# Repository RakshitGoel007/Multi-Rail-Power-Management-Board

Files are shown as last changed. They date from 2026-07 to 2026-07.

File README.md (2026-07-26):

# Multi-Rail Power Management Board

LTspice and KiCad portfolio project for a sequenced three-rail power-management block.

## Project Summary

This project converts a single 5 V input into three sequenced rails for an SoC + sensor cluster:

| Rail | Voltage | Purpose | Enable Time |
| --- | ---: | --- | ---: |
| Rail A | 1.2 V | SoC core | 0 ms |
| Rail B | 1.8 V | I/O logic | 2 ms |
| Rail C | 3.3 V | Sensors/camera | 4 ms |

The design includes input protection, regulator-stage modeling, output capacitance, equivalent loads, enable sequencing, Rail C load-step simulation, KiCad schematic capture, BOM files, and interview/report documentation.

## Repository Layout

```text
ltspice/   LTspice schematics, netlist, symbols, and vendor model files
kicad/     KiCad schematic project, symbol library, ERC report, exports
docs/      complete report, interview Q&A, portfolio summary, run guide
results/   simulation plots
bom/       project BOM
```

## Main Files

- `ltspice/PowerRails_Behavioral_Complete.asc`
- `ltspice/PowerRails_Behavioral_Complete.cir`
- `kicad/PowerRailsBoard_KiCad/PowerRailsBoard.kicad_pro`
- `kicad/PowerRailsBoard_KiCad/PowerRailsBoard.kicad_sch`
- `docs/Exhaustive_Project_Report.md`
- `docs/Exhaustive_Project_Report.pdf`
- `docs/Comprehensive_Interview_QA.md`
- `docs/Comprehensive_Interview_QA.pdf`
- `docs/Complete_Report_and_Interview_QA.pdf`
- `docs/Complete_Project_Report.md`
- `docs/Interview_Questions_and_Answers.md`
- `results/PowerRails_Sequencing_Plot.png`
- `results/RailC_Load_Transient_Plot.png`

## Validation

KiCad ERC result:

```text
0 errors, 0 warnings
```

The LTspice behavioral simulation is the recommended starting point because it does not depend on fragile vendor-symbol setup. Plot:

```text
V(RAIL_A_1V2)
V(RAIL_B_1V8)
V(RAIL_C_3V3)
V(EN_A)
V(EN_B)
V(EN_C)
```

## Engineering Note

The regulator part numbers are used for modeling and schematic practice. Before PCB fabrication, final regulator current ratings, thermal limits, package choices, and datasheet application circuits must be rechecked against the actual load requirements.

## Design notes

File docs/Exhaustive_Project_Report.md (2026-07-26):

# Exhaustive Project Report: Multi-Rail Power Management Board

Prepared for: Rakshit Goel  
Project type: hardware design, power electronics, schematic capture, simulation, and interview portfolio  
Main tools: LTspice, KiCad, TI regulator models, datasheets, behavioral simulation  
Repository: `Multi-Rail-Power-Management-Board`

## 1. Project Overview

This project is a multi-rail power management design for a small embedded system made from an SoC and a sensor/camera cluster. The board takes a single 5 V input and generates three regulated voltage rails:

| Rail | Voltage | Intended Load | Enable Order |
| --- | ---: | --- | ---: |
| Rail A | 1.2 V | SoC core logic | First |
| Rail B | 1.8 V | I/O logic, memory interface, IMU-style devices | Second |
| Rail C | 3.3 V | sensors, camera, peripheral modules | Third |

The core idea is not just to generate voltages. The project demonstrates an engineering workflow:

- define voltage/current requirements,
- choose a power architecture,
- model startup sequencing,
- simulate load transient behavior,
- capture a readable KiCad schematic,
- include protection and test points,
- prepare documentation and interview explanation material.

The project is portfolio-oriented. It is designed to show that the designer understands both circuit behavior and the practical workflow of building and explaining a hardware subsystem.

## 2. What The Project Does

At a system level, the project does the following:

1. Accepts a nominal 5 V input supply.
2. Provides reverse-polarity protection at the input.
3. Generates a 1.2 V rail for SoC core logic.
4. Generates a 1.8 V rail for I/O logic and low-voltage peripherals.
5. Generates a 3.3 V rail for sensors/camera/peripherals.
6. Sequences the rails in a controlled order.
7. Adds output capacitors to support transient current demand.
8. Adds equivalent loads for simulation and validation.
9. Adds a Rail C load-step event to represent a sensor/camera waking up.
10. Adds enable monitor signals so startup timing can be plotted clearly.
11. Provides a KiCad schematic with test points and a BOM.
12. Exports a schematic PDF, SVG/PNG preview, netlist, BOM, and ERC report.
13. Provides a complete report and interview question bank.

The LTspice simulation focuses on startup behavior and load transient response. The KiCad schematic focuses on readability, design intent, component organization, and bring-up/debug access.

## 3. Why Multi-Rail Power Exists

Modern embedded systems rarely run from one supply voltage. A typical SoC may have:

- a low-voltage core supply for internal logic,
- a separate I/O supply for interface pins,
- a higher peripheral supply for sensors, cameras, RF modules, or analog front ends.

Using separate rails allows each subsystem to receive the voltage it needs. It also improves control over noise, sequencing, power consumption, and debugging.

In this project:

- 1.2 V represents a core rail.
- 1.8 V represents an I/O rail.
- 3.3 V represents a peripheral/sensor rail.

This is a realistic split for many embedded boards.

## 4. Design Requirements

### 4.1 Electrical Requirements

| Requirement | Target |
| --- | --- |
| Input voltage | 5 V nominal |
| Output Rail A | 1.2 V |
| Output Rail B | 1.8 V |
| Output Rail C | 3.3 V |
| Rail A current target | 500 mA equivalent |
| Rail B current target | 600 mA equivalent |
| Rail C current target | 800 mA transient case |
| Startup sequence | A first, B second, C third |
| Rail B delay | about 2 ms after Rail A |
| Rail C delay | about 4 ms after Rail A |
| Rail C load step | 0.1 A to 0.8 A at 8 ms |
| Simulation duration | 20 ms transient |

### 4.2 Functional Requirements

The project must:

- show clear startup sequencing,
- include realistic rail names,
- include output capacitance,
- model expected load conditions,
- include transient response observation,
- include test points,
- be explainable in an interview,
- open reliably in LTspice and KiCad.

### 4.3 Documentation Requirements

The project must include:

- a technical report,
- an interview Q&A bank,
- a one-page summary,
- instructions for opening and running,
- BOM files,
- simulation plots,
- schematic exports.

## 5. Power Architecture

The architecture is:

```text
5 V input
  |
  +--> input protection
  |
  +--> Rail A regulator --> 1.2 V core rail
  |
  +--> Rail B regulator --> 1.8 V I/O rail
  |
  +--> Rail C regulator/load switch --> 3.3 V sensor rail
```

Rail A comes up first because SoC internal logic should be alive before I/O and peripherals are powered. Rail B comes second because I/O pads often depend on the core domain being valid. Rail C comes third because sensors/cameras can draw significant current and should not be powered before the processor/I/O side is ready.

## 6. Rail Definitions

### 6.1 Rail A: 1.2 V Core

Rail A is the first rail. It represents the SoC core supply. Core rails often power CPU logic, internal state machines, memory controllers, PLL blocks, or digital logic.

Design intent:

- start at 0 ms,
- settle near 1.2 V,
- support an equivalent 500 mA load,
- provide a reference for later rails.

Equivalent load:

```text
R = V / I = 1.2 V / 0.5 A = 2.4 ohm
```

### 6.2 Rail B: 1.8 V I/O

Rail B is the second rail. It represents low-voltage I/O logic or peripheral interfaces.

Design intent:

- start around 2 ms,
- settle near 1.8 V,
- support an equivalent 600 mA load,
- avoid powering I/O before the core rail.

Equivalent load:

```text
R = V / I = 1.8 V / 0.6 A = 3.0 ohm
```

### 6.3 Rail C: 3.3 V Sensor Rail

Rail C is the third rail. It represents sensors, camera modules, and other 3.3 V peripherals.

Design intent:

- start around 4 ms,
- settle near 3.3 V,
- support a transient load jump,
- include a load-switch concept for peripheral control.

Full-load equivalent resistance:

```text
R = V / I = 3.3 V / 0.8 A = 4.125 ohm
```

In the main simulation, Rail C uses a current load-step model because that better represents a sensor or camera suddenly waking up.

## 7. Why Sequencing Matters

Power sequencing is important because ICs are not always tolerant of arbitrary rail order. Incorrect sequencing can cause:

- back-powering through I/O pins,
- current injection through ESD diodes,
- undefined boot states,
- latch-up risk,
- peripherals starting before the controller is ready,
- increased inrush current,
- failed reset behavior.

The intended startup order is:

```text
Rail A: 1.2 V core       t = 0 ms
Rail B: 1.8 V I/O        t = 2 ms
Rail C: 3.3 V sensors    t = 4 ms
```

For power-down, the preferred order is normally reverse:

```text
Rail C off first
Rail B off second
Rail A off last
```

This prevents peripherals and I/O from remaining powered while the core logic is unavailable.

## 8. Component-Level Design

### 8.1 Input Protection

The schematic includes `D1 SS34`, a Schottky diode used for reverse-polarity protection. The purpose is to protect the board if the input supply is accidentally connected backwards.

Advantages:

- simple,
- cheap,
- easy to understand,
- robust for a student-level schematic.

Disadvantages:

- forward voltage drop,
- power loss,
- heating at high current.

Power loss estimate:

```text
P = I * Vf
```

If current is 1 A and diode drop is 0.4 V:

```text
P = 1 A * 0.4 V = 0.4 W
```

For a production board, a P-MOSFET ideal-diode style reverse-protection circuit would be more efficient.

### 8.2 Regulator Stages

The guide-selected regulators/models are:

| Ref | Part | Purpose |
| --- | --- | --- |
| U1 | TPS62203 | buck regulator reference for 3.3 V rail |
| U2 | TPS62240 | buck regulator reference for 1.8 V rail |
| U3 | TLV70012 | LDO reference for 1.2 V rail |

Important caveat:

The selected part numbers are useful for model practice and schematic learning, but a real fabricated board must verify regulator current ratings. If the actual rails require 500 mA, 600 mA, and 800 mA continuously, the selected parts may not all be suitable. A competent final design would select regulators with adequate current margin, thermal performance, and package capability.

### 8.3 Output Capacitors

Each rail uses a 22 uF output capacitor in the simulation. Output capacitors:

- reduce ripple,
- support transient load steps,
- improve local energy availability,
- affect regulator loop stability,
- reduce high-frequency impedance at the rail.

Ceramic X7R capacitors are used conceptually because they have good temperature behavior compared with lower-grade dielectrics.

Real-world note:

Ceramic capacitor effective capacitance decreases with DC bias. A 22 uF capacitor may behave like a much smaller capacitor at its operating voltage, depending on package and dielectric.

### 8.4 Equivalent Loads

Resistive loads are used for Rail A and Rail B:

| Rail | Voltage | Current | Load |
| --- | ---: | ---: | ---: |
| A | 1.2 V | 0.5 A | 2.4 ohm |
| B | 1.8 V | 0.6 A | 3.0 ohm |

Rail C includes a light load and a pulsed load step.

### 8.5 Rail C Load Step

Rail C models a sudden load increase:

```text
0.1 A light load -> 0.8 A active load
```

This represents a sensor/camera subsystem waking up or entering active mode.

The project measures:

- pre-step average voltage,
- minimum voltage during load step,
- recovered average voltage.

This shows whether the rail droops too much and whether it recovers.

### 8.6 Enable Monitor Signals

The LTspice schematic includes behavioral enable monitor sources:

```text
EN_A
EN_B
EN_C
```

These are not meant to be final production enable circuits. They are included so the startup sequence can be plotted clearly against the rail voltages.

In a real design, these enables could be produced by:

- RC delay circuits,
- power-good chaining,
- a microcontroller,
- a PMIC,
- a supervisor/sequencer IC.

## 9. LTspice Simulation

### 9.1 Main Files

```text
ltspice/PowerRails_Behavioral_Complete.asc
ltspice/PowerRails_Behavioral_Complete.cir
```

The `.asc` file is the visual schematic-style simulation. The `.cir` file is the companion plain netlist.

### 9.2 Why Behavioral Modeling Was Used

Vendor regulator models can be fragile. They may depend on exact subcircuit names, hidden pins, PSPICE compatibility, or symbol alignment. A behavioral model allows the project to validate the architecture first:

- startup order,
- expected output voltages,
- enable timing,
- load step behavior,
- measurement workflow.

The behavioral model is not a replacement for a final regulator simulation. It is a fast architecture-level verification step.

### 9.3 Behavioral Equations

The LTspice schematic uses function directives such as:

```spice
.func RA(t) if(t>=0,1.2,0)
.func RB(t) if(t>=2m,1.8,0)
.func RC(t) if(t>=4m,3.292,0)-if(t>=8m,if(t<12m,56m,0),0)
.func LOAD(t) if(t>=8m,if(t<12m,0.7,0),0)
```

This keeps the schematic visually clean because each behavioral source displays a short expression:

```spice
V=RA(time)
V=RB(time)
V=RC(time)
I=LOAD(time)
```

### 9.4 Simulation Command

```spice
.tran 20m startup
```

This runs a transient simulation from 0 ms to 20 ms and starts from supply startup conditions.

### 9.5 Signals To Plot

```text
V(RAIL_A_1V2)
V(RAIL_B_1V8)
V(RAIL_C_3V3)
V(EN_A)
V(EN_B)
V(EN_C)
I(IC_LOADSTEP)
```

### 9.6 Expected Results

Expected startup:

| Signal | Expected Behavior |
| --- | --- |
| `RAIL_A_1V2` | rises first to 1.2 V |
| `RAIL_B_1V8` | rises after about 2 ms |
| `RAIL_C_3V3` | rises after about 4 ms |
| `EN_A` | turns on at 0 ms |
| `EN_B` | turns on at 2 ms |
| `EN_C` | turns on at 4 ms |
| `I(IC_LOADSTEP)` | active around 8 ms to 12 ms |

### 9.7 Measurement Directives

The simulation includes:

```spice
.meas tran RailA_90pct_time WHEN V(RAIL_A_1V2)=1.08 RISE=1
.meas tran RailB_90pct_time WHEN V(RAIL_B_1V8)=1.62 RISE=1
.meas tran RailC_90pct_time WHEN V(RAIL_C_3V3)=2.97 RISE=1
.meas tran RailC_pre_step_avg AVG V(RAIL_C_3V3) FROM=7m TO=7.8m
.meas tran RailC_load_step_min MIN V(RAIL_C_3V3) FROM=8m TO=9m
.meas tran RailC_recovered_avg AVG V(RAIL_C_3V3) FROM=9m TO=12m
```

These measure:

- when each rail reaches 90% of nominal,
- Rail C voltage before the transient,
- Rail C minimum voltage during the load step,
- Rail C recovered average voltage after the step.

### 9.8 Acceptance Criteria

For this project:

- Rail A should reach 90% before Rail B begins.
- Rail B should reach 90% before Rail C begins.
- Rail C should show controlled droop during the load step.
- The simulation should be readable and repeatable.

For a production design, acceptance criteria would also include:

- ripple voltage limit,
- transient recovery time,
- overshoot limit,
- power-up monotonicity,
- thermal limit,
- efficiency target,
- EMI target.

## 10. KiCad Schematic Design

### 10.1 Main Files

```text
kicad/PowerRailsBoard_KiCad/PowerRailsBoard.kicad_pro
kicad/PowerRailsBoard_KiCad/PowerRailsBoard.kicad_sch
```

### 10.2 Exported Files

```text
kicad/PowerRailsBoard_KiCad/PowerRailsBoard_schematic.pdf
kicad/PowerRailsBoard_KiCad/PowerRailsBoard.svg.png
kicad/PowerRailsBoard_KiCad/PowerRailsBoard.net
kicad/PowerRailsBoard_KiCad/PowerRailsBoard_BOM_from_KiCad.csv
kicad/PowerRailsBoard_KiCad/ERC_report.txt
```

### 10.3 ERC Result

KiCad ERC result:

```text
0 errors, 0 warnings
```

This means the schematic has no KiCad-detected electrical rule problems in the current schematic-level representation.

### 10.4 What The KiCad Schematic Contains

The KiCad schematic includes:

- input connector,
- input reverse-polarity diode,
- input capacitor,
- regulator blocks,
- output capacitors,
- load resistors,
- Rail C P-MOSFET load switch,
- feedback divider representation,
- enable sequencing RC networks,
- test points,
- net labels,
- title notes.

### 10.5 Why Custom Symbols Were Used

The schematic uses custom local symbols in `RailProject.kicad_sym`. This reduces dependency issues. The schematic opens cleanly because it does not rely on missing external symbol libraries.

For a production schematic, the next step would be to replace simplified local regulator blocks with official manufacturer symbols and confirmed footprints.

## 11. BOM Summary

The BOM contains the main components:

| Ref | Part | Purpose |
| --- | --- | --- |
| U1 | TPS62203 | 3.3 V buck reference |
| U2 | TPS62240 | 1.8 V buck reference |
| U3 | TLV70012 | 1.2 V LDO reference |
| Q1 | AO3401 | P-MOSFET Rail C load switch |
| D1 | SS34 | reverse-polarity protection |
| C_IN | 10 uF X7R | input capacitor |
| C_OUT_A/B/C | 22 uF X7R | output capacitors |
| R_LOAD_A | 2.4 ohm | Rail A load |
| R_LOAD_B | 3.0 ohm | Rail B load |
| R_LOAD_C | 4.125 ohm/pulsed | Rail C load representation |

## 12. Important Engineering Caveats

### 12.1 Regulator Current Rating

The most important caveat is that the named parts must be checked against current requirements before fabrication. Model availability does not equal design suitability.

A stronger production design would select regulators with:

- rated output current above the maximum load,
- thermal margin,
- acceptable efficiency,
- available package and footprint,
- datasheet-supported inductor/capacitor values,
- stable control loop over expected load.

### 12.2 LDO Thermal Dissipation

If a 1.2 V rail is generated from 5 V using an LDO at 500 mA:

```text
P = (Vin - Vout) * I
P = (5 V - 1.2 V) * 0.5 A
P = 1.9 W
```

That is too high for many small packages. A real board would likely use a buck converter for 1.2 V or a two-stage approach.

### 12.3 Behavioral Simulation Limits

The behavioral LTspice model does not show:

- switching ripple,
- inductor current ripple,
- compensation loop behavior,
- switch-node ringing,
- layout parasitics,
- EMI,
- real startup soft-start details,
- regulator current limiting.

It is still valuable because it validates architecture and timing.

### 12.4 RC Sequencing Tolerance

RC delays are approximate. Real delays vary due to:

- resistor tolerance,
- capacitor tolerance,
- capacitor leakage,
- temperature,
- enable threshold variation,
- input ramp rate.

For production, a sequencer IC is more reliable.

## 13. PCB Layout Considerations

If this schematic is moved to PCB layout, key rules are:

1. Place input capacitors close to regulator VIN and GND pins.
2. Keep high-current loops short.
3. Keep buck switch nodes small.
4. Route feedback traces away from switch nodes.
5. Use a solid ground plane.
6. Use wide traces or pours for high-current rails.
7. Place output capacitors close to regulator outputs.
8. Keep analog/sensitive nodes away from noisy switching paths.
9. Add thermal copper for regulators and diode.
10. Keep test points accessible.

For a two-layer board, layout is possible but harder. For a cleaner power design, a four-layer board with solid ground and power planes is preferable.

## 14. Bring-Up Plan

### 14.1 Before Power-On

Check:

- visual inspection,
- diode orientation,
- capacitor polarity if any polarized parts exist,
- regulator pinout,
- shorts between each rail and ground,
- continuity of input and ground,
- correct component values.

### 14.2 First Power-On

Use:

- current-limited bench supply,
- low current limit at first,
- oscilloscope on rail test points,
- multimeter for steady-state checks.

Procedure:

1. Apply 5 V with low current limit.
2. Confirm no excessive current.
3. Measure `VIN_5V`.
4. Probe `EN_A`, `EN_B`, `EN_C`.
5. Probe `RAIL_A_1V2`, `RAIL_B_1V8`, `RAIL_C_3V3`.
6. Confirm order and final voltages.
7. Increase load slowly.
8. Test Rail C load transient.

### 14.3 Measurements To Capture

Capture:

- startup sequence waveform,
- rise time of each rail,
- final DC voltage,
- load transient droop,
- recovery time,
- ripple,
- regulator temperature.

## 15. Failure Modes And Debug Strategy

| Symptom | Possible Cause | Debug Step |
| --- | --- | --- |
| Rail missing | regulator disabled, wrong footprint, short, no input | check VIN and EN pin |
| Rail low | overload, wrong feedback, current limit | remove load, inspect feedback |
| Rail noisy | poor layout, missing capacitor, unstable loop | check capacitor placement and values |
| Startup wrong order | RC timing error, threshold variation | probe enable pins |
| Diode hot | excessive current or high voltage drop | measure current and diode drop |
| Rail C droops too much | insufficient capacitance or slow regulator | increase capacitance or choose faster regulator |
| Board current too high | short, wrong part orientation, load too heavy | current-limit and isolate rails |

## 16. Repository Deliverables

| Path | Purpose |
| --- | --- |
| `README.md` | GitHub landing page |
| `ltspice/PowerRails_Behavioral_Complete.asc` | main LTspice visual simulation |
| `ltspice/PowerRails_Behavioral_Complete.cir` | companion netlist |
| `ltspice/PowerRails_REAL.asc` | real-model starter schematic |
| `ltspice/*.asy` | LTspice symbols |
| `ltspice/*.lib` | LTspice model libraries |
| `kicad/PowerRailsBoard_KiCad/PowerRailsBoard.kicad_pro` | KiCad project |
| `kicad/PowerRailsBoard_KiCad/PowerRailsBoard.kicad_sch` | KiCad schematic |
| `kicad/PowerRailsBoard_KiCad/ERC_report.txt` | ERC validation |
| `kicad/PowerRailsBoard_KiCad/PowerRailsBoard_schematic.pdf` | schematic PDF export |
| `kicad/PowerRailsBoard_KiCad/PowerRailsBoard_BOM_from_KiCad.csv` | KiCad BOM export |
| `bom/PowerRails_BOM.csv` | project-level BOM |
| `results/PowerRails_Sequencing_Plot.png` | sequencing simulation plot |
| `results/RailC_Load_Transient_Plot.png` | load transient plot |
| `docs/Exhaustive_Project_Report.md` | detailed project report |
| `docs/Comprehensive_Interview_QA.md` | interview preparation bank |

## 17. What This Project Demonstrates

This project demonstrates:

- power rail planning,
- rail sequencing,
- load calculation,
- transient simulation,
- behavioral modeling,
- schematic organization,
- BOM creation,
- ERC checking,
- test point planning,
- awareness of real-world limitations,
- ability to communicate an engineering design.

The strongest interview point is that the project does not blindly claim perfection. It clearly separates:

- what is proven by the behavioral simulation,
- what is represented by the KiCad schematic,
- what must still be checked before fabrication.

That is how a competent engineer presents a design.

## 18. Short Interview Summary

This project is a multi-rail power management block for an SoC and sensor cluster. It takes a 5 V input and creates 1.2 V, 1.8 V, and 3.3 V rails. The rails are sequenced so the core rail turns on first, then I/O, then sensors. I simulated the startup sequence and a 3.3 V load transient in LTspice, captured an ERC-clean schematic in KiCad, included input protection, enable delay networks, output capacitors, loads, and test points, and documented the design limitations. The next production step would be replacing the learning-model regulator choices with current-rated regulators, assigning final footprints, doing PCB layout, and validating sequencing, ripple, transient response, and temperature on the bench.

## 19. Final Conclusion

The project successfully shows a complete power-management design workflow. It is not just a schematic; it includes requirements, architecture, simulation, schematic capture, validation exports, documentation, and interview preparation.

The design is appropriate as a university-level hardware portfolio project. It shows practical understanding of power sequencing, regulator selection tradeoffs, transient behavior, and bring-up planning. The final design should not be fabricated without regulator current-rating review and thermal analysis, but as an interview project it is technically defensible, well-scoped, and explainable.

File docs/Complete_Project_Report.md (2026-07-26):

# Multi-Rail Power Management Board for SoC + Sensor Cluster

Prepared for: Rakshit Goel  
Project type: Hardware interview portfolio project  
Main tools: LTspice, KiCad, TI regulator models/datasheets

## 1. Executive Summary

This project designs a three-rail power management block from a single 5 V input. The target load is a small SoC plus sensor cluster needing a clean 1.2 V core rail, 1.8 V I/O rail, and 3.3 V sensor rail. The design focuses on correct power sequencing, load decoupling, test-point visibility, and a clear bring-up/debug story.

The key design rule is:

- Rail A, 1.2 V core, turns on first at 0 ms.
- Rail B, 1.8 V I/O, turns on second at about 2 ms.
- Rail C, 3.3 V sensors/camera, turns on third at about 4 ms.
- Power-down should happen in reverse order: 3.3 V off first, 1.2 V off last.

This sequencing avoids powering I/O pads before the core logic is alive, which reduces the risk of latch-up, back-powering, and undefined boot states.

## 2. Requirements

| Rail | Voltage | Max Current | Load Powered | Regulator Type | Enable Time |
| --- | ---: | ---: | --- | --- | ---: |
| Input | 5 V | 2 A | Board input | USB/input source | Always on |
| Rail A | 1.2 V | 500 mA | SoC core | Low-noise LDO | 0 ms |
| Rail B | 1.8 V | 600 mA | I/O logic, IMU | Synchronous buck | 2 ms |
| Rail C | 3.3 V | 800 mA | Sensors, camera | Synchronous buck | 4 ms |

Protection and bring-up requirements:

- Reverse-polarity protection on the 5 V input.
- Load switch on the 3.3 V sensor rail.
- Test points on VIN, every output rail, and every enable net.
- Output capacitors on all rails.
- Simulated sequencing and load transient response before schematic capture.

## 3. Architecture

The board accepts 5 V from USB or a bench supply. The 5 V input feeds three regulators:

- `U3 TLV70012`: creates the 1.2 V core rail.
- `U2 TPS62240`: creates the 1.8 V rail.
- `U1 TPS62203`: creates the 3.3 V rail.

The rail enable order is controlled by delayed enable signals:

- `EN_A`: immediate enable for 1.2 V.
- `EN_B`: delayed enable for 1.8 V.
- `EN_C`: delayed enable for 3.3 V.

In a real schematic, the delay can be made using RC networks feeding the regulator enable pins. For a production board, a dedicated power sequencer or supervisor IC would be more repeatable over voltage, temperature, and part tolerance.

## 4. Component Selection and BOM

| Ref | Part | Function | Package | Notes |
| --- | --- | --- | --- | --- |
| U1 | TI TPS62203 | 3.3 V synchronous buck | SOT23-5 | Used as guide-selected buck model |
| U2 | TI TPS62240 | 1.8 V synchronous buck | SOT23-5 / WSON | Used as guide-selected buck model |
| U3 | TI TLV70012 | 1.2 V LDO | SOT23-5 / SC70 / WSON family | Used as guide-selected LDO model |
| Q1 | AO3401 | P-MOSFET load switch | SOT23-3 | Controls/hot-plug protects Rail C |
| D1 | SS34 | Reverse-polarity Schottky diode | SMA / DO-214 | Input protection |
| C_IN | 10 uF ceramic X7R | Input bulk/decoupling | 0805/1206 | Place near regulator inputs |
| C_OUT_A | 22 uF ceramic X7R | 1.2 V output capacitor | 0805/1206 | Simulation uses 22 uF |
| C_OUT_B | 22 uF ceramic X7R | 1.8 V output capacitor | 0805/1206 | Simulation uses 22 uF |
| C_OUT_C | 22 uF ceramic X7R | 3.3 V output capacitor | 0805/1206 | Simulation uses 22 uF |
| R_LOAD_A | 2.4 ohm | 1.2 V full-load equivalent | 0603/0805, power-rated | 1.2 V / 0.5 A |
| R_LOAD_B | 3.0 ohm | 1.8 V full-load equivalent | 0603/0805, power-rated | 1.8 V / 0.6 A |
| I_LOAD_C | PULSE current sink | 3.3 V load transient | Simulation element | 0.1 A to 0.8 A |

Important engineering caveat:

The guide-selected regulator part numbers are useful for model practice, but their current ratings must be checked before fabrication. TPS62203/TPS62240 are low-current buck parts, and TLV700 is a low-current LDO family. If the final board must truly supply 500 mA, 600 mA, and 800 mA continuously, choose higher-current regulator alternatives and re-run thermal and transient checks. This is a good interview point because it shows that the BOM was not accepted blindly.

## 5. Load Calculations

Equivalent load resistance is calculated using:

```text
R = V / I
```

| Rail | Voltage | Current | Equivalent Load |
| --- | ---: | ---: | ---: |
| Rail A | 1.2 V | 0.5 A | 2.4 ohm |
| Rail B | 1.8 V | 0.6 A | 3.0 ohm |
| Rail C | 3.3 V | 0.8 A | 4.125 ohm |

For the load-transient simulation, Rail C uses a current sink instead of a fixed 4.125 ohm resistor:

```spice
PULSE(0.1 0.8 8m 10u 10u 4m 8m)
```

This means the sensor rail draws 0.1 A at light load, then jumps to 0.8 A at 8 ms.

## 6. LTspice Simulation

The main simulation deliverables are:

- `PowerRails_Behavioral_Complete.asc`
- `PowerRails_Behavioral_Complete.cir`

The behavioral simulation is intentionally robust. It avoids depending on custom symbols or vendor-model compatibility and instead represents each regulator as an ideal sequenced voltage source with small output resistance and output capacitance.

Run command:

```spice
.tran 20m startup
```

Signals to plot:

```text
V(RAIL_A_1V2)
V(RAIL_B_1V8)
V(RAIL_C_3V3)
V(EN_A)
V(EN_B)
V(EN_C)
I(IC_LOADSTEP)
```

Expected sequencing result:

- `RAIL_A_1V2` rises first and settles near 1.2 V.
- `RAIL_B_1V8` starts after 2 ms and settles near 1.8 V.
- `RAIL_C_3V3` starts after 4 ms and settles near 3.3 V.
- At 8 ms, Rail C load current steps from 0.1 A to 0.8 A.

The simulation includes these measurement commands:

```spice
.meas tran RailA_90pct_time WHEN V(RAIL_A_1V2)=1.08 RISE=1
.meas tran RailB_90pct_time WHEN V(RAIL_B_1V8)=1.62 RISE=1
.meas tran RailC_90pct_time WHEN V(RAIL_C_3V3)=2.97 RISE=1
.meas tran RailC_pre_step_avg AVG V(RAIL_C_3V3) FROM=7m TO=7.8m
.meas tran RailC_load_step_min MIN V(RAIL_C_3V3) FROM=8m TO=9m
.meas tran RailC_recovered_avg AVG V(RAIL_C_3V3) FROM=9m TO=12m
```

Acceptance criteria:

- Rail A must be above 90% before Rail B starts.
- Rail B must be above 90% before Rail C starts.
- Rail C transient droop should remain within about +/-3% of 3.3 V for this portfolio-level model.

## 7. KiCad Schematic

The KiCad deliverable is located in:

```text
PowerRailsBoard_KiCad/
```

Main files:

- `PowerRailsBoard.kicad_pro`: KiCad project file.
- `PowerRailsBoard.kicad_sch`: ERC-clean schematic.
- `PowerRailsBoard_schematic.pdf`: exported schematic PDF.
- `PowerRailsBoard.net`: exported netlist.
- `PowerRailsBoard_BOM_from_KiCad.csv`: BOM exported directly from KiCad.
- `ERC_report.txt`: KiCad ERC report showing 0 errors and 0 warnings.

The schematic contains:

- One 5 V input connector or power symbol.
- `D1 SS34` reverse-polarity protection at the input.
- `U3 TLV70012` or a corrected higher-current LDO for 1.2 V.
- `U2 TPS62240` or a corrected higher-current buck for 1.8 V.
- `U1 TPS62203` or a corrected higher-current buck for 3.3 V.
- `Q1 AO3401` P-MOSFET load switch on Rail C.
- RC enable-delay networks for `EN_A`, `EN_B`, and `EN_C`.
- 10 uF input capacitors and 22 uF output capacitors.
- Test points on `VIN_5V`, `EN_A`, `EN_B`, `EN_C`, `RAIL_A_1V2`, `RAIL_B_1V8`, and `RAIL_C_3V3`.
- Clear net labels and annotated reference designators.

Recommended KiCad net names:

```text
VIN_5V
EN_A
EN_B
EN_C
RAIL_A_1V2
RAIL_B_1V8
RAIL_C_3V3
GND
```

ERC target:

- Achieved: KiCad CLI ERC reports 0 errors and 0 warnings.
- Generic embedded symbols are used so the schematic opens without depending on missing external part symbols.
- Exact manufacturer footprints should be assigned before PCB layout/fabrication.

## 8. Protection and Bring-Up Strategy

Reverse-polarity protection:

- `SS34` protects against accidental reverse input.
- A Schottky diode is simple but drops voltage and dissipates power.
- For higher efficiency, an ideal-diode controller or P-MOSFET reverse-protection circuit is better.

Rail C load switch:

- `AO3401` P-MOSFET can disconnect the 3.3 V sensor cluster.
- This helps with hot-plug protection and allows firmware-controlled sensor power.

Test points:

- Test points make bring-up measurable.
- During bench validation, probe `VIN_5V`, all enable pins, and all output rails with an oscilloscope.

## 9. What To Say In An Interview

Use this short explanation:

This project converts a 5 V input into three sequenced rails for an SoC and sensor cluster. I chose a 1.2 V core rail, 1.8 V I/O rail, and 3.3 V sensor rail. The core rail comes up first, then I/O, then sensors, because powering I/O before the core can cause undefined logic states or latch-up. I verified the sequencing in LTspice and added a Rail C load-transient test to model a sensor waking up. For a fabricated version, I would update the regulator current ratings, run thermal checks, and validate the rails on the bench with a scope and electronic load.

## 10. Limitations and Next Steps

Current limitations:

- Behavioral LTspice model is used for the main proof, so it does not show real switching ripple.
- Vendor model integration is prepared, but real-model convergence must be checked separately.
- The guide-selected part numbers should be current-rating checked before fabrication.
- PCB layout is not fully routed; the current KiCad deliverable is an ERC-clean schematic-level design.

Next steps:

- Replace guide-selected parts with regulators rated for the required currents.
- Assign exact footprints in KiCad.
- Do a rough 2-layer placement pass.
- For a real board, prefer a 4-layer PCB with solid ground planes for better return paths and lower noise.
- Fabricate and validate sequencing, ripple, load transient, and temperature rise on the bench.

## 11. Project Files

| File | Purpose |
| --- | --- |
| `PowerRails_Behavioral_Complete.asc` | Main LTspice schematic-style simulation, no custom symbols required |
| `PowerRails_Behavioral_Complete.cir` | Same simulation as a plain LTspice netlist |
| `PowerRails_REAL_clean.asc` | Starter schematic using custom regulator symbols |
| `PowerRailsBoard_KiCad/PowerRailsBoard.kicad_pro` | KiCad project |
| `PowerRailsBoard_KiCad/PowerRailsBoard.kicad_sch` | ERC-clean KiCad schematic |
| `PowerRailsBoard_KiCad/PowerRailsBoard_schematic.pdf` | Exported KiCad schematic PDF |
| `PowerRailsBoard_KiCad/ERC_report.txt` | KiCad ERC report, 0 errors and 0 warnings |
| `PowerRailsBoard_KiCad/PowerRailsBoard.net` | Exported KiCad netlist |
| `PowerRailsBoard_KiCad/PowerRailsBoard_BOM_from_KiCad.csv` | BOM exported from KiCad |
| `TPS62203.asy` | LTspice symbol for TPS62203 subcircuit |
| `TPS62240_TRANS.asy` | LTspice symbol for TPS62240 subcircuit |
| `TLV70012.asy` | LTspice symbol for TLV70012 subcircuit |
| `TI_regulator_models/` | Downloaded TI model ZIPs, extracted libraries, and datasheets |
| `Complete_Project_Report.md` | This report |
| `Interview_Questions_and_Answers.md` | Interview question bank |
| `PowerRails_BOM.csv` | BOM table for project documentation |

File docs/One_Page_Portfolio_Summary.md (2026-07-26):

# Multi-Rail Power Management Board: Portfolio Summary

## Problem

A small SoC plus sensor cluster needs three clean, correctly sequenced rails from a single 5 V input: 1.2 V for the core, 1.8 V for I/O logic, and 3.3 V for sensors/camera. Incorrect sequencing can power I/O before the core, creating latch-up, back-powering, or undefined boot-state risk.

## Approach

The design uses a 5 V input and creates:

| Rail | Voltage | Load | Purpose | Enable Time |
| --- | ---: | ---: | --- | ---: |
| Rail A | 1.2 V | 500 mA | SoC core | 0 ms |
| Rail B | 1.8 V | 600 mA | I/O logic, IMU | 2 ms |
| Rail C | 3.3 V | 800 mA | Sensors/camera | 4 ms |

The rail order is core first, I/O second, sensors third. Power-down should happen in reverse order.

## Simulation

The LTspice behavioral simulation proves startup sequencing and a Rail C load transient. The main files are:

```text
PowerRails_Behavioral_Complete.asc
PowerRails_Behavioral_Complete.cir
```

Expected plots:

- `PowerRails_Sequencing_Plot.png`: 1.2 V rises first, 1.8 V starts at 2 ms, 3.3 V starts at 4 ms.
- `RailC_Load_Transient_Plot.png`: 3.3 V rail responds to a 0.1 A to 0.8 A load step at 8 ms and stays inside the +/-3% target band.

## Schematic and Bring-Up Planning

The KiCad schematic is included in `PowerRailsBoard_KiCad/` and passes KiCad CLI ERC with 0 errors and 0 warnings. It includes reverse-polarity protection, output capacitors, RC enable-delay networks, a P-MOSFET load switch on the 3.3 V sensor rail, and test points on all rails and enable nets.

## Engineering Caveat

The guide-selected regulator model parts are useful for simulation practice, but current ratings must be checked before fabrication. For a real PCB, I would replace any under-rated regulators with parts rated above the required load current and re-run thermal/transient validation.

## Next Steps

Assign exact footprints, do a rough placement/routing pass, and validate the fabricated board with a scope and electronic load.

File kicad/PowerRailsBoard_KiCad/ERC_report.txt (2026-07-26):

ERC report (2026-07-26T10:34:43, Encoding UTF8)
Report includes: Errors, Warnings

***** Sheet /

 ** ERC messages: 0  Errors 0  Warnings 0

 ** Ignored checks:
    - Global label only appears once in the schematic
    - Four connection points are joined together
    - SPICE model issue
    - Assigned footprint doesn't match footprint filters

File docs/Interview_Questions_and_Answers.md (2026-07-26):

# Interview Questions and Answers: Multi-Rail Power Management Board

Use this as a rehearsal sheet. The answers are written in a spoken-interview style: short, direct, and technically defensible.

## Basic Level

### 1. What is the project about?

It is a multi-rail power management board that takes a 5 V input and generates three sequenced rails: 1.2 V, 1.8 V, and 3.3 V for an SoC plus sensor cluster.

### 2. Why are there three different voltage rails?

Different parts of a system need different supply voltages. The SoC core may need 1.2 V, I/O logic may need 1.8 V, and sensors or camera modules often need 3.3 V.

### 3. What are the three output rails?

Rail A is 1.2 V, Rail B is 1.8 V, and Rail C is 3.3 V.

### 4. What is the input voltage?

The board uses a 5 V input, similar to a USB or bench-supply input.

### 5. What is a regulator?

A regulator converts an input voltage into a stable output voltage, even when load current or input voltage changes within allowed limits.

### 6. What is an LDO?

An LDO is a low-dropout linear regulator. It gives a clean output with low noise but is less efficient when the voltage drop and current are large.

### 7. What is a buck converter?

A buck converter is a switching regulator that steps a higher voltage down to a lower voltage efficiently using an inductor, switches, and capacitors.

### 8. Why use a buck converter for 1.8 V and 3.3 V?

Buck converters are more efficient than LDOs when supplying higher current. They waste less power because they switch energy through an inductor instead of burning the voltage difference as heat.

### 9. Why use an LDO for the 1.2 V rail?

The 1.2 V core rail can be noise-sensitive, so an LDO is attractive because it has lower output noise than a switching converter. The tradeoff is efficiency and heat.

### 10. What is power sequencing?

Power sequencing means turning rails on and off in a controlled order instead of letting all supplies rise randomly.

### 11. What is the sequence in this project?

The 1.2 V core rail turns on first at 0 ms, the 1.8 V rail turns on at about 2 ms, and the 3.3 V rail turns on at about 4 ms.

### 12. Why does the core rail turn on first?

The core rail powers internal logic. If I/O rails turn on first, I/O pins can be powered while the core is off, which can cause undefined behavior, back-powering, or latch-up risk.

### 13. What is a test point?

A test point is a small accessible node on the PCB where an engineer can probe voltage or signals during bring-up and debugging.

### 14. Why add output capacitors?

Output capacitors reduce ripple, help transient response, and provide local charge when the load current changes quickly.

### 15. What does LTspice help prove?

LTspice helps prove that the rails turn on in the correct order and that the outputs behave acceptably during load changes.

## Intermediate Level

### 16. How did you calculate the load resistors?

I used Ohm's law: `R = V / I`. For example, the 1.2 V rail at 0.5 A gives `1.2 / 0.5 = 2.4 ohm`.

### 17. What are the equivalent loads for the rails?

Rail A uses 2.4 ohm for 500 mA. Rail B uses 3.0 ohm for 600 mA. Rail C equivalent full load is 4.125 ohm for 800 mA, but the simulation uses a pulsed current source for the transient test.

### 18. What is a load transient?

A load transient is a sudden change in load current, such as a camera or sensor waking up and drawing much more current.

### 19. How did you simulate the Rail C load transient?

I used a current sink with `PULSE(0.1 0.8 8m 10u 10u 4m 8m)`, so the 3.3 V rail current jumps from 0.1 A to 0.8 A at 8 ms.

### 20. What is acceptable transient droop?

For this portfolio-level design, I used about +/-3% of nominal voltage as a practical acceptance target. For 3.3 V, that is about +/-99 mV.

### 21. Why does output voltage dip during a load step?

When current suddenly increases, the regulator and output capacitor cannot respond instantly. The capacitor supplies charge briefly, and parasitic resistance/inductance causes a temporary voltage drop.

### 22. How can you reduce transient droop?

Increase output capacitance, choose capacitors with lower ESR/ESL, improve PCB layout, use a faster regulator, or reduce the load-step edge rate.

### 23. What does capacitor ESR mean?

ESR is equivalent series resistance. It is the small resistance inside a real capacitor, and it contributes to ripple and transient voltage jumps.

### 24. Why use ceramic X7R capacitors?

X7R ceramics offer good capacitance stability across temperature compared with cheaper dielectrics, and they have low ESR for decoupling.

### 25. Why should capacitors be close to regulator pins?

Short placement reduces parasitic inductance and resistance, improving transient response and reducing noise/ripple.

### 26. What is an enable pin?

An enable pin turns a regulator on or off. It is useful for sequencing, power saving, and fault handling.

### 27. How does an RC delay work?

A resistor charges a capacitor slowly. The enable pin turns on when the capacitor voltage crosses the enable threshold.

### 28. What is the approximate RC delay equation?

For a rising RC node, delay is approximately `t = -RC ln(1 - Vth/Vin)`, where `Vth` is the enable threshold.

### 29. Why is an RC delay not perfect?

Resistor tolerance, capacitor tolerance, leakage, temperature, and enable threshold variation all affect the actual delay.

### 30. What is better than RC sequencing for production?

A dedicated power sequencer, supervisor IC, or PMIC is better because thresholds and timing are more controlled and repeatable.

### 31. Why add reverse-polarity protection?

It protects the board if the input supply is accidentally connected backwards.

### 32. What is the downside of a Schottky diode for reverse protection?

It drops voltage and dissipates power. At high current, the heat loss can become significant.

### 33. What is a better reverse-protection method?

A P-MOSFET or ideal-diode controller can provide reverse protection with much lower voltage drop and power loss.

### 34. Why add a P-MOSFET load switch on Rail C?

It lets the design disconnect or sequence the sensor cluster separately, which helps hot-plug protection and firmware-controlled power gating.

### 35. Why are net labels important?

Clear net labels make schematics easier to review, simulate, debug, and probe during bring-up.

## Advanced Level

### 36. What is latch-up?

Latch-up is a failure condition where parasitic structures inside an IC conduct heavily, often triggered by invalid voltage conditions or injection currents. It can damage the chip if current is not limited.

### 37. How can incorrect rail sequencing cause latch-up?

If I/O pins are powered before the core or internal protection structures are biased incorrectly, current can flow through ESD diodes or parasitic paths into unpowered domains.

### 38. What does back-powering mean?

Back-powering means an unpowered rail or device is unintentionally powered through an I/O pin, protection diode, or another unintended path.

### 39. What would you check before choosing a regulator?

Input range, output voltage, current rating, efficiency, thermal performance, transient response, stability requirements, package, layout difficulty, cost, and availability.

### 40. What is the main thermal issue with using an LDO from 5 V to 1.2 V at 500 mA?

The LDO power loss is `(5 - 1.2) * 0.5 = 1.9 W`, which is too high for many small packages without serious thermal design.

### 41. What would you change for the 1.2 V rail if efficiency matters?

I would use a buck converter for 5 V to 1.2 V, possibly followed by a low-noise LDO only if the core supply needs extra noise filtering.

### 42. What issue did you find in the guide-selected parts?

The listed regulator parts are useful for learning and model availability, but their current ratings must be checked. For a fabricated board, I would choose regulators rated above the required 500 mA, 600 mA, and 800 mA loads.

### 43. Why does a buck converter need an inductor?

The inductor stores and releases energy each switching cycle, smoothing current and allowing efficient voltage conversion.

### 44. What happens if the buck inductor value is too small?

Inductor ripple current increases, which can increase output ripple, stress components, and possibly cause unstable or noisy operation.

### 45. What happens if the inductor value is too large?

Transient response can become slower, size/cost may increase, and the regulator may not behave as intended with its compensation.

### 46. What does regulator stability depend on?

It depends on the control loop, output capacitor value, ESR, inductor value for bucks, load range, and layout parasitics.

### 47. What is switching ripple?

Switching ripple is periodic voltage variation caused by the regulator switching action, inductor ripple current, and output capacitor impedance.

### 48. Why does the behavioral simulation not show true switching ripple?

The behavioral model represents ideal sequenced voltage outputs with small output resistance. It proves timing and load response conceptually, but it does not model real switching devices or PWM behavior.

### 49. Why use behavioral simulation at all?

It lets me validate architecture and sequencing quickly without getting blocked by vendor model compatibility. Later I can replace the blocks with detailed regulator models.

### 50. How would you validate this on a real bench?

I would power the board from a current-limited bench supply, probe enable and rail test points with an oscilloscope, apply load steps with an electronic load, and compare timing, droop, ripple, and temperature against the simulation and datasheets.

### 51. What scope measurements would you capture?

Startup sequencing, rail rise time, steady-state ripple, load-transient undershoot/overshoot, recovery time, power-down order, and switching node waveform for buck regulators.

### 52. What layout practices matter most for buck converters?

Keep the high di/dt input loop small, place input capacitors close to VIN/GND pins, keep the switch node short, use a solid ground plane, and route feedback away from noisy nodes.

### 53. Why is the switch node noisy?

The switch node rapidly transitions between ground and input voltage, creating high dv/dt and high-frequency noise.

### 54. How should the feedback trace be routed?

It should be short, quiet, and away from the switch node and inductor. It should sense the output voltage at a clean point near the output capacitor/load.

### 55. Why might a 4-layer PCB be better than a 2-layer PCB?

A 4-layer board can provide solid ground and power planes, lower return impedance, better EMI behavior, and easier separation of noisy and sensitive nodes.

### 56. What is power-good?

Power-good is a regulator output signal that indicates whether the rail is within regulation. It can be used to sequence later rails or reset logic.

### 57. Why is power-good sequencing better than fixed time delay?

It waits for the previous rail to actually be valid instead of assuming it became valid after a fixed time.

### 58. What failure modes would you design for?

Input reverse polarity, overcurrent, shorted output, thermal shutdown, unstable regulator loop, failed enable sequencing, and sensor hot-plug current surges.

### 59. How would you improve the Rail C load switch?

I would add a gate resistor, gate pull-up/down as appropriate, consider inrush limiting, check MOSFET SOA, and verify that VGS ratings are not exceeded.

### 60. How does this project connect to hardware interviews?

It demonstrates requirements capture, regulator selection, power sequencing, simulation, schematic planning, BOM thinking, protection design, test-point strategy, and honest discussion of next validation steps.

## Deep-Dive Challenge Questions

### 61. If Rail B starts before Rail A settles, what would you change?

I would increase the Rail B enable delay, or better, gate Rail B enable using Rail A's power-good signal so sequencing depends on actual rail validity.

### 62. If Rail C droop is too high during load step, what are your first three fixes?

I would increase output capacitance, reduce output capacitor ESR/ESL with better capacitor choice and placement, and choose a regulator with better transient response or higher current capability.

### 63. How do you calculate LDO efficiency?

For an LDO, approximate efficiency is `Vout / Vin` if ground current is ignored. For 1.2 V from 5 V, that is only about 24%.

### 64. Why is an LDO still sometimes used despite poor efficiency?

It is simple, low-noise, and can be acceptable for low current rails or post-regulation after a buck converter.

### 65. How would you make this design more production-ready?

Use current-rated regulators, power-good based sequencing, thermal analysis, EMI-aware layout, proper protection, worst-case tolerance analysis, and bench validation against datasheet limits.

### 66. What is the strongest part of this project to discuss in an interview?

The strongest part is the engineering reasoning: I define rail requirements, enforce safe sequencing, simulate startup and load transient behavior, and identify current-rating and thermal risks before fabrication.

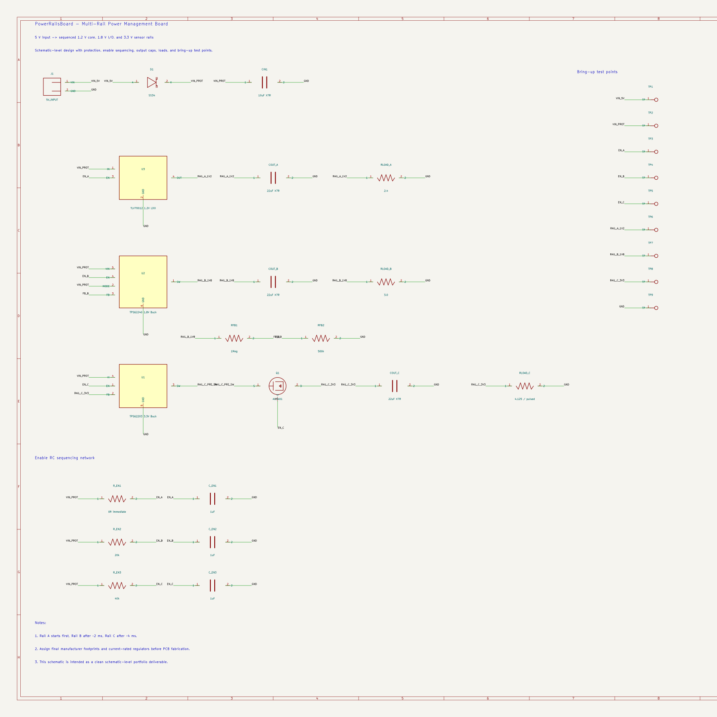
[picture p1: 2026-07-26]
kicad/PowerRailsBoard_KiCad/PowerRailsBoard.svg.png

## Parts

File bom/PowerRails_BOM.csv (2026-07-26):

Ref | Part | Function | Package | Value_or_Rating | Notes
U1 | TI TPS62203 | 3.3 V synchronous buck | SOT23-5 | 3.3 V output | Guide-selected model part; check current rating before fabrication
U2 | TI TPS62240 | 1.8 V synchronous buck | SOT23-5 or WSON | Adjustable to 1.8 V | Guide-selected model part; check current rating before fabrication
U3 | TI TLV70012 | 1.2 V low-noise LDO | SOT23-5 or family package | 1.2 V output | Guide-selected model part; check current rating before fabrication
Q1 | AO3401 or similar P-MOSFET | 3.3 V sensor rail load switch | SOT23-3 | Logic-level P-MOSFET | Used for sensor hot-plug/power gating
D1 | SS34 Schottky diode | Reverse-polarity input protection | SMA/DO-214 | 3 A class Schottky | Simple input protection
CIN1 | MLCC X7R | Input capacitor | 0805/1206 | 10 uF | Place close to regulator inputs
COUT_A | MLCC X7R | 1.2 V output capacitor | 0805/1206 | 22 uF | Behavioral simulation value
COUT_B | MLCC X7R | 1.8 V output capacitor | 0805/1206 | 22 uF | Behavioral simulation value
COUT_C | MLCC X7R | 3.3 V output capacitor | 0805/1206 | 22 uF | Behavioral simulation value
RLOAD_A | Resistor | 1.2 V equivalent load | Power-rated resistor | 2.4 ohm | Models 500 mA load
RLOAD_B | Resistor | 1.8 V equivalent load | Power-rated resistor | 3.0 ohm | Models 600 mA load
ILOAD_C | Current source | 3.3 V transient load | LTspice element | PULSE 0.1 A to 0.8 A | Models sensor wake-up current step
R_EN_A | Resistor | Enable delay network | 0603 | Small or 0 ohm equivalent | Immediate enable
R_EN_B | Resistor | Enable delay network | 0603 | Example 10k to 20k | Target about 2 ms delay
R_EN_C | Resistor | Enable delay network | 0603 | Example 20k to 40k | Target about 4 ms delay
C_EN_A | Capacitor | Enable delay network | 0603 | Small or omitted | Immediate enable
C_EN_B | Capacitor | Enable delay network | 0603 | 0.1 uF to 1 uF range | Tune for about 2 ms delay
C_EN_C | Capacitor | Enable delay network | 0603 | 0.1 uF to 1 uF range | Tune for about 4 ms delay
TP_VIN | Test point | Input measurement | Test point | VIN_5V | Bring-up debug
TP_A | Test point | Rail A measurement | Test point | RAIL_A_1V2 | Bring-up debug
TP_B | Test point | Rail B measurement | Test point | RAIL_B_1V8 | Bring-up debug
TP_C | Test point | Rail C measurement | Test point | RAIL_C_3V3 | Bring-up debug
TP_EN_A | Test point | Enable A measurement | Test point | EN_A | Bring-up debug
TP_EN_B | Test point | Enable B measurement | Test point | EN_B | Bring-up debug
TP_EN_C | Test point | Enable C measurement | Test point | EN_C | Bring-up debug

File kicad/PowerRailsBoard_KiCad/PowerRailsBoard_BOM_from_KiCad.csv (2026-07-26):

Refs | Value | Footprint | Qty | DNP
CIN1 | 10uF X7R | Capacitor_SMD:C_0805_2012Metric | 1
COUT_A? | 22uF X7R | Capacitor_SMD:C_0805_2012Metric | 1
COUT_B? | 22uF X7R | Capacitor_SMD:C_0805_2012Metric | 1
COUT_C? | 22uF X7R | Capacitor_SMD:C_0805_2012Metric | 1
C_EN1 | 1uF | Capacitor_SMD:C_0805_2012Metric | 1
C_EN2 | 1uF | Capacitor_SMD:C_0805_2012Metric | 1
C_EN3 | 1uF | Capacitor_SMD:C_0805_2012Metric | 1
D1 | SS34 | Diode_SMD:D_SMA | 1
J1 | 5V_INPUT | Connector_PinHeader_2.54mm:PinHeader_1x02_P2.54mm_Vertical | 1
Q1 | AO3401 | Package_TO_SOT_SMD:SOT-23 | 1
RFB1 | 1Meg | Resistor_SMD:R_0603_1608Metric | 1
RFB2 | 500k | Resistor_SMD:R_0603_1608Metric | 1
RLOAD_A? | 2.4 | Resistor_SMD:R_0603_1608Metric | 1
RLOAD_B? | 3.0 | Resistor_SMD:R_0603_1608Metric | 1
RLOAD_C? | 4.125 / pulsed | Resistor_SMD:R_0603_1608Metric | 1
R_EN1 | 0R immediate | Resistor_SMD:R_0603_1608Metric | 1
R_EN2 | 20k | Resistor_SMD:R_0603_1608Metric | 1
R_EN3 | 40k | Resistor_SMD:R_0603_1608Metric | 1
TP1 | VIN_5V | TestPoint:TestPoint_Pad_D1.5mm | 1
TP2 | VIN_PROT | TestPoint:TestPoint_Pad_D1.5mm | 1
TP3 | EN_A | TestPoint:TestPoint_Pad_D1.5mm | 1
TP4 | EN_B | TestPoint:TestPoint_Pad_D1.5mm | 1
TP5 | EN_C | TestPoint:TestPoint_Pad_D1.5mm | 1
TP6 | RAIL_A_1V2 | TestPoint:TestPoint_Pad_D1.5mm | 1
TP7 | RAIL_B_1V8 | TestPoint:TestPoint_Pad_D1.5mm | 1
TP8 | RAIL_C_3V3 | TestPoint:TestPoint_Pad_D1.5mm | 1
TP9 | GND | TestPoint:TestPoint_Pad_D1.5mm | 1
U1 | TPS62203 3.3V Buck | Package_TO_SOT_SMD:SOT-23-5 | 1
U2 | TPS62240 1.8V Buck | Package_TO_SOT_SMD:SOT-23-5 | 1
U3 | TLV70012 1.2V LDO | Package_TO_SOT_SMD:SOT-23-5 | 1

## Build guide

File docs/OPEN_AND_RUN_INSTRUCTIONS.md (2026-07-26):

# How To Open and Run the Project on Mac LTspice

Use this GitHub project folder:

```text
Multi-Rail-Power-Management-Board
```

## Best File To Open

Open this file first:

```text
ltspice/PowerRails_Behavioral_Complete.asc
```

This is the safest file because it does not need custom symbols.

## If Double-Click Does Not Work

1. Open LTspice first.
2. Click:

```text
File -> Open
```

3. Go to:

```text
Multi-Rail-Power-Management-Board -> ltspice
```

4. Select:

```text
PowerRails_Behavioral_Complete.asc
```

5. Click Open.

## Run Simulation

Click the running-man button.

## Plot These Signals

In the waveform window, add these traces:

```text
V(rail_a_1v2)
V(rail_b_1v8)
V(rail_c_3v3)
```

Also useful:

```text
V(en_a)
V(en_b)
V(en_c)
I(ic_loadstep)
```

## What You Should See

- 1.2 V turns on first at 0 ms.
- 1.8 V turns on second at 2 ms.
- 3.3 V turns on third at 4 ms.
- Rail C load current jumps at 8 ms.

## Files Not To Start With

Do not start with:

```text
old downloaded files
ltspice/PowerRails_REAL.asc
```

Those are older or real-model starter files. Use the behavioral complete file first.

## KiCad Project

Open this in KiCad:

```text
kicad/PowerRailsBoard_KiCad/PowerRailsBoard.kicad_pro
```

The KiCad schematic has already been checked with KiCad CLI:

```text
0 errors, 0 warnings
```

Exported KiCad files are also inside `kicad/PowerRailsBoard_KiCad/`:

```text
PowerRailsBoard_schematic.pdf
PowerRailsBoard.net
PowerRailsBoard_BOM_from_KiCad.csv
ERC_report.txt
```

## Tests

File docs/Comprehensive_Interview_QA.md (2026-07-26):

# Comprehensive Interview Questions And Answers

Project: Multi-Rail Power Management Board  
Use case: hardware, embedded systems, power electronics, LTspice, KiCad, bring-up, and debugging interviews

## How To Use This Document

Start with the easy questions until the project story feels natural. Then move to intermediate and advanced sections. In an interview, do not recite everything. Give a direct answer first, then expand only if the interviewer asks.

## Easy Level: Project Basics

### 1. What is this project about?

It is a multi-rail power management board. It takes a 5 V input and generates three sequenced rails: 1.2 V, 1.8 V, and 3.3 V for an SoC plus sensor cluster.

### 2. Why did you build it?

I built it to demonstrate power-rail planning, sequencing, LTspice simulation, KiCad schematic capture, BOM creation, and hardware bring-up thinking.

### 3. What are the output voltages?

The outputs are 1.2 V, 1.8 V, and 3.3 V.

### 4. What does each rail power?

The 1.2 V rail represents SoC core logic, the 1.8 V rail represents I/O logic, and the 3.3 V rail represents sensors or camera peripherals.

### 5. What is the input voltage?

The input is a nominal 5 V supply, similar to USB or a bench supply.

### 6. What is power sequencing?

Power sequencing is turning power rails on and off in a controlled order.

### 7. What is the startup order?

The 1.2 V core rail starts first, the 1.8 V I/O rail starts second, and the 3.3 V sensor rail starts third.

### 8. Why does the core rail start first?

The core logic should be alive before I/O and peripherals are powered. This reduces the risk of back-powering, undefined logic states, and latch-up.

### 9. What tools did you use?

I used LTspice for simulation and KiCad for schematic capture and ERC checking.

### 10. What is LTspice used for in this project?

LTspice is used to simulate rail startup timing and the Rail C load transient.

### 11. What is KiCad used for in this project?

KiCad is used to create the schematic, assign symbols, export a netlist/BOM/PDF, and run electrical rule checking.

### 12. What does ERC mean?

ERC means Electrical Rules Check. It checks schematic-level electrical issues such as unconnected pins, conflicting pin types, and other schematic problems.

### 13. Did the KiCad schematic pass ERC?

Yes. The exported ERC report shows 0 errors and 0 warnings.

### 14. What is a regulator?

A regulator converts an input voltage into a stable output voltage.

### 15. What is an LDO?

An LDO is a low-dropout linear regulator. It is simple and low-noise, but it can waste power as heat.

### 16. What is a buck converter?

A buck converter is a switching regulator that efficiently steps a higher voltage down to a lower voltage.

### 17. Why use capacitors on the outputs?

Output capacitors reduce ripple and help supply current during fast load changes.

### 18. What is a test point?

A test point is a probe-accessible node used during measurement and debugging.

### 19. What is the project’s strongest point?

The strongest point is that it shows a complete workflow: requirements, simulation, schematic, validation reports, BOM, documentation, and interview explanation.

### 20. What is the simplest way to explain the project?

It is a 5 V input power board that creates three controlled rails for an embedded system and verifies their startup order in LTspice.

## Intermediate Level: Design Choices

### 21. Why are multiple rails needed in an SoC system?

Different sections of an SoC need different voltages. Core logic often needs a low voltage like 1.2 V, I/O may need 1.8 V, and external sensors often need 3.3 V.

### 22. Why not power all rails at the same time?

Some ICs require a specific rail order. If I/O powers before the core, current can flow through protection structures and cause undefined behavior.

### 23. What is back-powering?

Back-powering happens when an unpowered rail or chip is unintentionally powered through another signal path, often through I/O protection diodes.

### 24. What is latch-up?

Latch-up is a destructive condition where parasitic internal structures in an IC conduct heavily. It can happen due to invalid voltage conditions or injected current.

### 25. How can bad sequencing cause latch-up?

If I/O pins are powered while the core is off, internal structures may be biased incorrectly, allowing current paths that should not exist.

### 26. Why is Rail C turned on last?

Rail C powers sensors/peripherals. These loads should start after the core and I/O are ready, and they may draw significant transient current.

### 27. What is a load transient?

A load transient is a sudden change in current demand.

### 28. Why simulate a Rail C load transient?

Sensors or cameras may suddenly wake up and draw much more current. The simulation checks whether the 3.3 V rail droops too much.

### 29. What is the Rail C load step?

Rail C is modeled as stepping from a light load to a heavier active load around 8 ms.

### 30. How did you calculate load resistance?

I used Ohm’s law: `R = V / I`.

### 31. What is the Rail A load resistance?

For 1.2 V at 0.5 A, `R = 1.2 / 0.5 = 2.4 ohm`.

### 32. What is the Rail B load resistance?

For 1.8 V at 0.6 A, `R = 1.8 / 0.6 = 3.0 ohm`.

### 33. What is the Rail C full-load resistance?

For 3.3 V at 0.8 A, `R = 3.3 / 0.8 = 4.125 ohm`.

### 34. Why is Rail C modeled with a current source?

A current source is better for modeling a dynamic load like a sensor waking up because the current demand changes with time.

### 35. What does the 22 uF output capacitor do?

It provides local charge, reduces ripple, and helps reduce voltage droop during transient events.

### 36. Why use X7R ceramic capacitors?

X7R capacitors have better temperature stability than lower-grade dielectrics and are common for decoupling.

### 37. What is ESR?

ESR is equivalent series resistance. It is the effective resistance inside a capacitor and affects ripple and transient voltage drop.

### 38. What is ESL?

ESL is equivalent series inductance. It limits how well a capacitor responds at very high frequencies.

### 39. Why place capacitors near regulator pins?

Short placement reduces parasitic inductance and resistance, improving transient response and reducing noise.

### 40. Why include reverse-polarity protection?

It protects the board if the input supply is connected backwards.

### 41. What is the downside of a Schottky diode for input protection?

It has a forward voltage drop and dissipates heat.

### 42. What is a better production reverse-protection method?

A P-MOSFET ideal-diode style circuit or ideal diode controller gives lower voltage drop and better efficiency.

### 43. Why include a P-MOSFET load switch?

It allows the sensor rail to be disconnected, sequenced, or power-gated.

### 44. What does an enable pin do?

An enable pin turns a regulator on or off.

### 45. How can an RC delay create sequencing?

A resistor charges a capacitor. The regulator enable pin turns on when the capacitor voltage crosses its threshold.

### 46. What is the approximate RC delay formula?

For a charging capacitor, `t = -RC ln(1 - Vth/Vin)`.

### 47. Why are RC delays not exact?

They vary with resistor tolerance, capacitor tolerance, leakage, temperature, and enable threshold variation.

### 48. What is better than RC sequencing for production?

A power sequencer IC, supervisor, PMIC, or microcontroller-controlled enable sequence is more precise.

### 49. Why include test points on enable nets?

Enable test points let me verify that the sequence is actually happening at the regulator control pins.

### 50. Why include test points on every rail?

They make bring-up and debugging easier because every important voltage can be probed directly.

## Intermediate Level: LTspice And Simulation

### 51. Why use behavioral sources in LTspice?

Behavioral sources make the architecture easy to simulate without getting blocked by fragile vendor model setup.

### 52. Does the behavioral simulation model real switching ripple?

No. It models startup timing and load behavior, but not actual buck switching ripple or compensation loop details.

### 53. Why is that acceptable for this stage?

At the architecture stage, the main goal is to verify sequencing and load response conceptually. Detailed regulator simulation can come later.

### 54. What does `.tran 20m startup` do?

It runs a transient simulation for 20 ms and starts from initial startup conditions.

### 55. What signals should be plotted?

Plot the three rail voltages and the three enable signals: `V(RAIL_A_1V2)`, `V(RAIL_B_1V8)`, `V(RAIL_C_3V3)`, `V(EN_A)`, `V(EN_B)`, and `V(EN_C)`.

### 56. What do the `.meas` commands do?

They automatically measure rail startup times and Rail C voltage behavior before/during/after the load step.

### 57. Why measure 90% rail time?

90% of nominal is a common practical threshold for determining when a rail is mostly up.

### 58. What is 90% of 1.2 V?

`0.9 * 1.2 = 1.08 V`.

### 59. What is 90% of 1.8 V?

`0.9 * 1.8 = 1.62 V`.

### 60. What is 90% of 3.3 V?

`0.9 * 3.3 = 2.97 V`.

### 61. Why did you move long formulas into `.func` directives?

To keep the LTspice schematic visually clean. The source values stay short, while the detailed equations live in a directive block.

### 62. What is the purpose of `V=RA(time)`?

It tells the behavioral source to output the Rail A voltage according to the `RA(t)` function.

### 63. Why are enable signals included as separate sources?

They make the intended sequence visible in the waveform plot.

### 64. How would you improve the simulation for production?

Use verified manufacturer models, include inductors and feedback components, model input supply ramp, include ESR/ESL, and run corner cases.

### 65. What corner cases would you simulate?

Minimum/maximum input voltage, light/full load, startup into load, output short behavior, temperature extremes, capacitor tolerance, and sequencing tolerance.

## Advanced Level: Regulator And Power Electronics

### 66. Why might an LDO from 5 V to 1.2 V be thermally bad?

The power loss is `(5 - 1.2) * 0.5 = 1.9 W`, which is too high for many small packages.

### 67. What would you use instead for high-current 1.2 V?

I would use a buck converter, possibly followed by a low-noise LDO if the rail needs extra filtering.

### 68. What is buck converter efficiency?

Efficiency is output power divided by input power. A buck converter is usually much more efficient than an LDO for high voltage drop and high current.

### 69. What is the purpose of the inductor in a buck converter?

The inductor stores and releases energy each switching cycle, smoothing current and enabling efficient voltage conversion.

### 70. What happens if the inductor is too small?

Ripple current increases, which can increase ripple, losses, current stress, and possibly instability.

### 71. What happens if the inductor is too large?

Transient response can become slower, size and cost increase, and the regulator may not operate optimally.

### 72. What is switch-node ringing?

It is high-frequency oscillation at the switching node caused by parasitic inductance and capacitance.

### 73. Why is the switch node noisy?

It has fast voltage transitions and high di/dt current loops.

### 74. How do you reduce switch-node noise?

Keep the switch node copper small, minimize loop area, use good grounding, and follow datasheet layout recommendations.

### 75. What is loop compensation?

Loop compensation shapes the regulator feedback loop so the output remains stable over load, capacitor, and input conditions.

### 76. What affects regulator stability?

Output capacitor value, ESR, inductor value, feedback network, load range, internal compensation, and layout parasitics.

### 77. What is load regulation?

Load regulation describes how much output voltage changes as load current changes.

### 78. What is line regulation?

Line regulation describes how much output voltage changes as input voltage changes.

### 79. What is dropout voltage?

Dropout voltage is the minimum voltage difference required between input and output for an LDO to regulate correctly.

### 80. What is quiescent current?

Quiescent current is the current consumed by the regulator itself to operate.

### 81. What is soft-start?

Soft-start controls how quickly a regulator output rises, reducing inrush current and overshoot.

### 82. Why does startup inrush matter?

Large inrush current can trip the supply, stress components, or pull down other rails.

### 83. What is output ripple?

Output ripple is AC variation on top of the DC output voltage.

### 84. How would you measure ripple correctly?

Use an oscilloscope with short ground spring or coax method, proper bandwidth limit if needed, and probe close to the capacitor.

### 85. Why is probing technique important?

A long probe ground lead adds inductance and can show false ringing/noise.

### 86. What is a power-good signal?

Power-good indicates that a regulator output is within a valid range. It can be used to enable the next rail.

### 87. Why is power-good chaining better than fixed RC delay?

It waits for the previous rail to actually be valid instead of only waiting a fixed time.

### 88. What is UVLO?

UVLO means undervoltage lockout. It prevents operation when input voltage is too low.

### 89. What is current limit?

Current limit protects the regulator and load by limiting output current during overload or short circuit.

### 90. What is thermal shutdown?

Thermal shutdown turns off or limits a device when it gets too hot.

## KiCad, Documentation, And Workflow

### 91. Why did you use KiCad?

KiCad is a standard open-source EDA tool for schematic capture and PCB design.

### 92. Why did you make custom symbols?

Custom local symbols avoid missing-library problems and keep the schematic portable.

### 93. What does the KiCad ERC prove?

It proves there are no detected schematic electrical-rule violations in the current schematic representation.

### 94. Does ERC prove the circuit will work?

No. ERC catches schematic consistency issues, not full electrical performance or layout correctness.

### 95. Why export a schematic PDF?

A PDF is easy to review, share, and attach to reports or interview portfolios.

### 96. Why include a BOM?

A BOM shows part choices, reference designators, functions, packages, and project organization.

### 97. What makes a schematic visually good?

Clear left-to-right flow, readable labels, grouped functions, minimal wire crossings, proper net names, and uncluttered notes.

### 98. What was cleaned in the LTspice schematic?

Long formulas were moved into `.func` directives, duplicated labels were removed, rails were spaced out, and directives were grouped separately.

### 99. What was cleaned in the KiCad schematic?

Symbols were made more recognizable, labels were spaced away from pins, the sheet size was increased, and ERC was kept clean.

### 100. Why is documentation important?

Documentation proves that the designer understands the design, not just that files exist.

## Deep Interview Questions

### 101. If the final loads are 500 mA, 600 mA, and 800 mA, what is your biggest concern?

The biggest concern is regulator current and thermal rating. The guide-selected parts must be verified or replaced with parts that can safely supply those currents.

### 102. Would you fabricate this exact board?

Not without final regulator selection, datasheet component values, footprint verification, thermal checks, and PCB layout review.

### 103. What would you say if an interviewer points out the regulator current mismatch?

I would say that is a valid catch. In this project the parts were guide/model references, and the report explicitly notes that production parts must be current-rated. That shows I understand the difference between a learning schematic and a fabrication-ready design.

### 104. How would you choose final regulators?

I would define input range, output voltage, max current, ripple limit, efficiency target, package constraints, thermal environment, cost, availability, and then compare datasheet-recommended application circuits.

### 105. How much current margin would you prefer?

I would usually choose a regulator with comfortable margin above expected maximum current, depending on thermal conditions and transient requirements.

### 106. What thermal checks would you run?

Estimate power loss, junction temperature rise, package thermal resistance, copper area, airflow, and worst-case ambient temperature.

### 107. How do you estimate LDO junction temperature?

Calculate power loss, multiply by thermal resistance, and add ambient temperature: `Tj = Ta + P * thetaJA`.

### 108. How would you validate sequencing on hardware?

Use an oscilloscope to probe all enable pins and output rails at test points during power-up and power-down.

### 109. How would you validate load transient?

Use an electronic load to step current and capture voltage droop and recovery on the oscilloscope.

### 110. What would you check if Rail B starts before Rail A is stable?

Check the enable timing circuit, RC values, enable thresholds, power-good signals, and input ramp behavior.

### 111. What would you check if Rail C droops too much?

Check output capacitance, capacitor ESR/ESL, regulator transient response, layout, load step magnitude, and current limit.

### 112. What would you check if a rail oscillates?

Check regulator stability, output capacitor value/ESR, feedback routing, layout, and datasheet compensation guidance.

### 113. What layout issue can break a buck converter?

Large high-current loop area or poor switch-node layout can create noise, ringing, EMI, and instability.

### 114. Why is a ground plane important?

A ground plane provides low-impedance return paths, reduces noise, and improves thermal spreading.

### 115. How would you handle analog sensors on the 3.3 V rail?

I might add filtering, local decoupling, ferrite bead isolation, or a low-noise LDO if the sensor is noise-sensitive.

### 116. What is the difference between schematic correctness and layout correctness?

Schematic correctness means the logical circuit connections are right. Layout correctness means physical placement, routing, grounding, thermal, and noise behavior are right.

### 117. Why include both `.asc` and `.cir` files?

The `.asc` is easier to view and edit visually. The `.cir` is a plain-text companion netlist useful for review and fallback simulation.

### 118. What would make this project stronger?

A routed PCB, regulator replacement with current-rated parts, detailed ripple simulation, real bench measurements, and thermal images would make it stronger.

### 119. What did you learn from the project?

I learned how to organize a power tree, plan sequencing, build a readable LTspice simulation, clean a KiCad schematic, and document engineering limitations honestly.

### 120. Give the final 30-second pitch.

This is a multi-rail power board for an SoC and sensor cluster. It takes 5 V and generates 1.2 V, 1.8 V, and 3.3 V rails with controlled startup sequencing. I simulated the startup and sensor-load transient in LTspice, created an ERC-clean KiCad schematic with protection, output capacitors, load elements, enable networks, and test points, and documented the design with BOM, reports, plots, and interview Q&A. The project demonstrates architecture-level power design and a realistic hardware workflow, while clearly identifying what must be upgraded before fabrication.

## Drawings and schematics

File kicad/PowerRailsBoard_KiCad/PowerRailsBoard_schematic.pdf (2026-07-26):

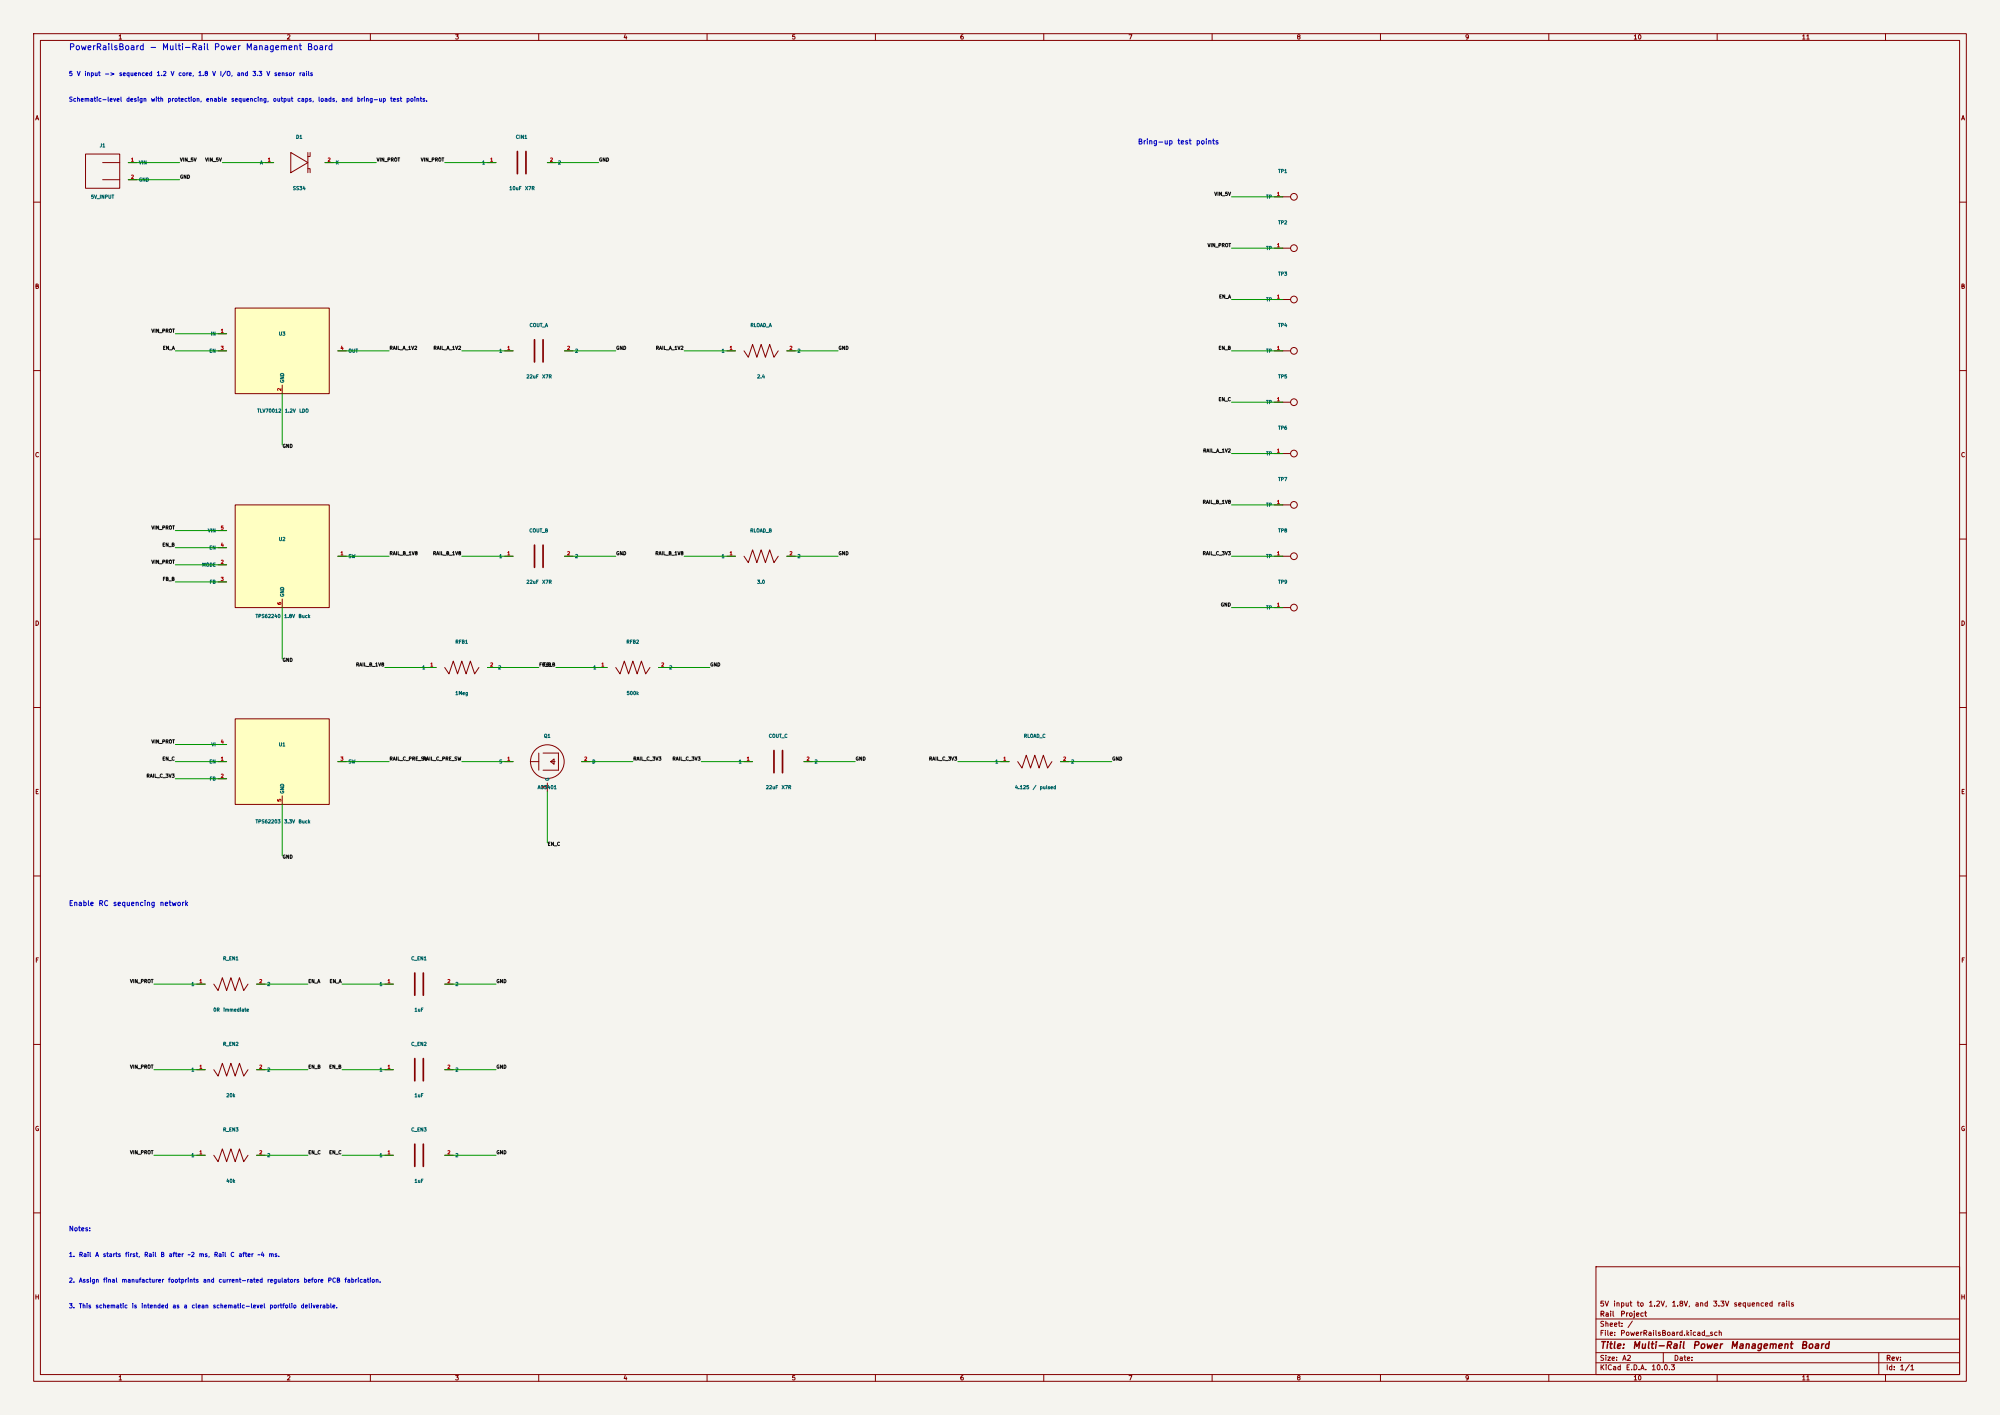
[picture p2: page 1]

RAIL_A_1V2 PowerRailsBoard - Multi-Rail Power Management Board

Schematic-level design with protection, enable sequencing, output caps, loads, and bring-up test points.

Enable RC sequencing network

2. Assign final manufacturer footprints and current-rated regulators before PCB fabrication. 1. Rail A starts first, Rail B after ~2 ms, Rail C after ~4 ms. Notes:

3. This schematic is intended as a clean schematic-level portfolio deliverable.

5V input to 1.2V, 1.8V, and 3.3V sequenced rails
Rail Project
Sheet: /
File: PowerRailsBoard.kicad_sch
Title: Multi-Rail Power Management Board

Size: A2 | Rev:
KiCad E.D.A. 10.0.3 | Id: 1/1
